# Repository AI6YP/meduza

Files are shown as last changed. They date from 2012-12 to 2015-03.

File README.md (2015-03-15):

## Meduza

Miniature control/logger board. Part of the Naut /nøyːt/ project.

### PCB v1

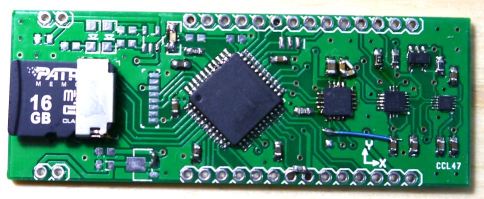
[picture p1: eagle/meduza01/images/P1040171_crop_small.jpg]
Meduza PCB top

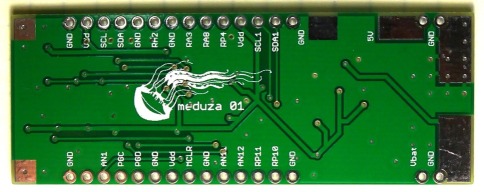
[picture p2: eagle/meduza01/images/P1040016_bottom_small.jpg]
Meduza PCB bottom


[Schematic (PDF)](eagle/meduza01/meduza01.pdf)

#### Features
 * Microchip microcontroller: [PIC24FJ64GA104](http://www.microchip.com/mymicrochip/filehandler.aspx?ddocname=en544252) / [DSPIC33EP128MC204](http://www.microchip.com/mymicrochip/filehandler.aspx?ddocname=en556386)
 * IRDA transceiver (2 Mibit/s) [TFDU6300](http://media.digikey.com/pdf/Data%20Sheets/Vishay%20Semiconductors/TFDU6300.pdf)
 * 3D Magnetometer [MAG3110L](http://cache.freescale.com/files/sensors/doc/data_sheet/MAG3110.pdf)
 * 3D Accelerometer [MMA8452QL](http://cache.freescale.com/files/sensors/doc/data_sheet/MMA8452Q.pdf)
 * 3D Giro [L3G4200D](http://www.st.com/web/en/resource/technical/document/datasheet/CD00265057.pdf)
 * temperature sensor [MCP9800](http://www.microchip.com/mymicrochip/filehandler.aspx?ddocname=en021183)
 * 1-cell LiPo battery PMIC [MCP73831T](http://www.microchip.com/mymicrochip/filehandler.aspx?ddocname=en025112)
 * microSD card socket (up-to 32GB)
 * analog/digital IO for externals sensors
 * Inductive charging circuitry (external)

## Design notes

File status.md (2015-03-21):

## Prototypes

### v1.03
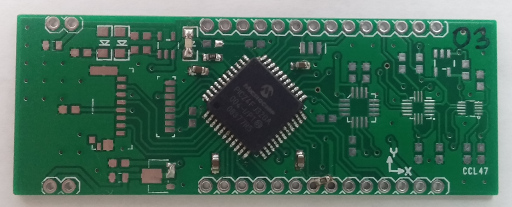
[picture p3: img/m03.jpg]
Meduza v1.03


* [PIC24FJ32GA004](http://ww1.microchip.com/downloads/en/DeviceDoc/39881e.pdf) - [3003h Errata](http://ww1.microchip.com/downloads/en/DeviceDoc/80000470h.pdf)

### v1.04
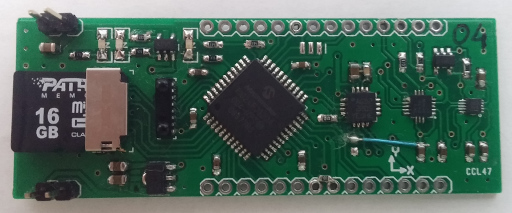
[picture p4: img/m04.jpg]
Meduza v1.04


* [PIC24FJ32GA004](http://ww1.microchip.com/downloads/en/DeviceDoc/39881e.pdf) - [3003h Errata](http://ww1.microchip.com/downloads/en/DeviceDoc/80000470h.pdf)
* IRDA transceiver (2 Mibit/s) [TFDU6300](http://media.digikey.com/pdf/Data%20Sheets/Vishay%20Semiconductors/TFDU6300.pdf)
* 3D Magnetometer [MAG3110L](http://cache.freescale.com/files/sensors/doc/data_sheet/MAG3110.pdf)
* 3D Accelerometer [MMA8452QL](http://cache.freescale.com/files/sensors/doc/data_sheet/MMA8452Q.pdf)
* 3D Giro [L3G4200D](http://www.st.com/web/en/resource/technical/document/datasheet/CD00265057.pdf)
* temperature sensor [MCP9800](http://www.microchip.com/mymicrochip/filehandler.aspx?ddocname=en021183)
* 1-cell LiPo battery PMIC [MCP73831T](http://www.microchip.com/mymicrochip/filehandler.aspx?ddocname=en025112)
* microSD card socket (up-to 32GB)

### v1.05
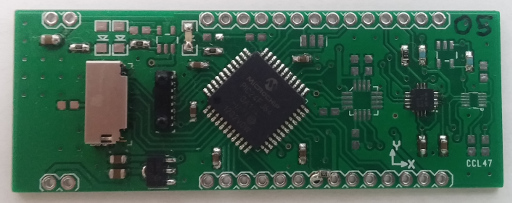
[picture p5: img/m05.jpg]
Meduza v1.05


* [PIC24FJ64GA004](http://ww1.microchip.com/downloads/en/DeviceDoc/39881e.pdf) - new
* IRDA transceiver (2 Mibit/s) [TFDU6300](http://media.digikey.com/pdf/Data%20Sheets/Vishay%20Semiconductors/TFDU6300.pdf)
* -
* 3D Accelerometer [MMA8452QL](http://cache.freescale.com/files/sensors/doc/data_sheet/MMA8452Q.pdf)
* -
* -
* -
* microSD card socket (up-to 32GB)

### v1.06
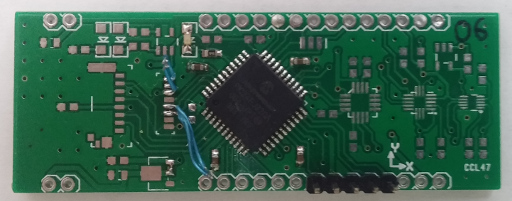
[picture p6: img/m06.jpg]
Meduza v1.06


* [PIC24FJ32GA004](http://ww1.microchip.com/downloads/en/DeviceDoc/39881e.pdf) - [3003h Errata](http://ww1.microchip.com/downloads/en/DeviceDoc/80000470h.pdf)

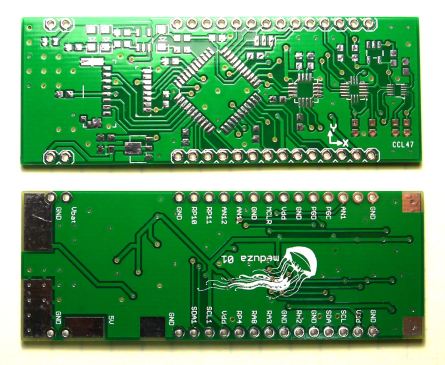
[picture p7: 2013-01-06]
eagle/meduza01/images/P1040016_small.jpg

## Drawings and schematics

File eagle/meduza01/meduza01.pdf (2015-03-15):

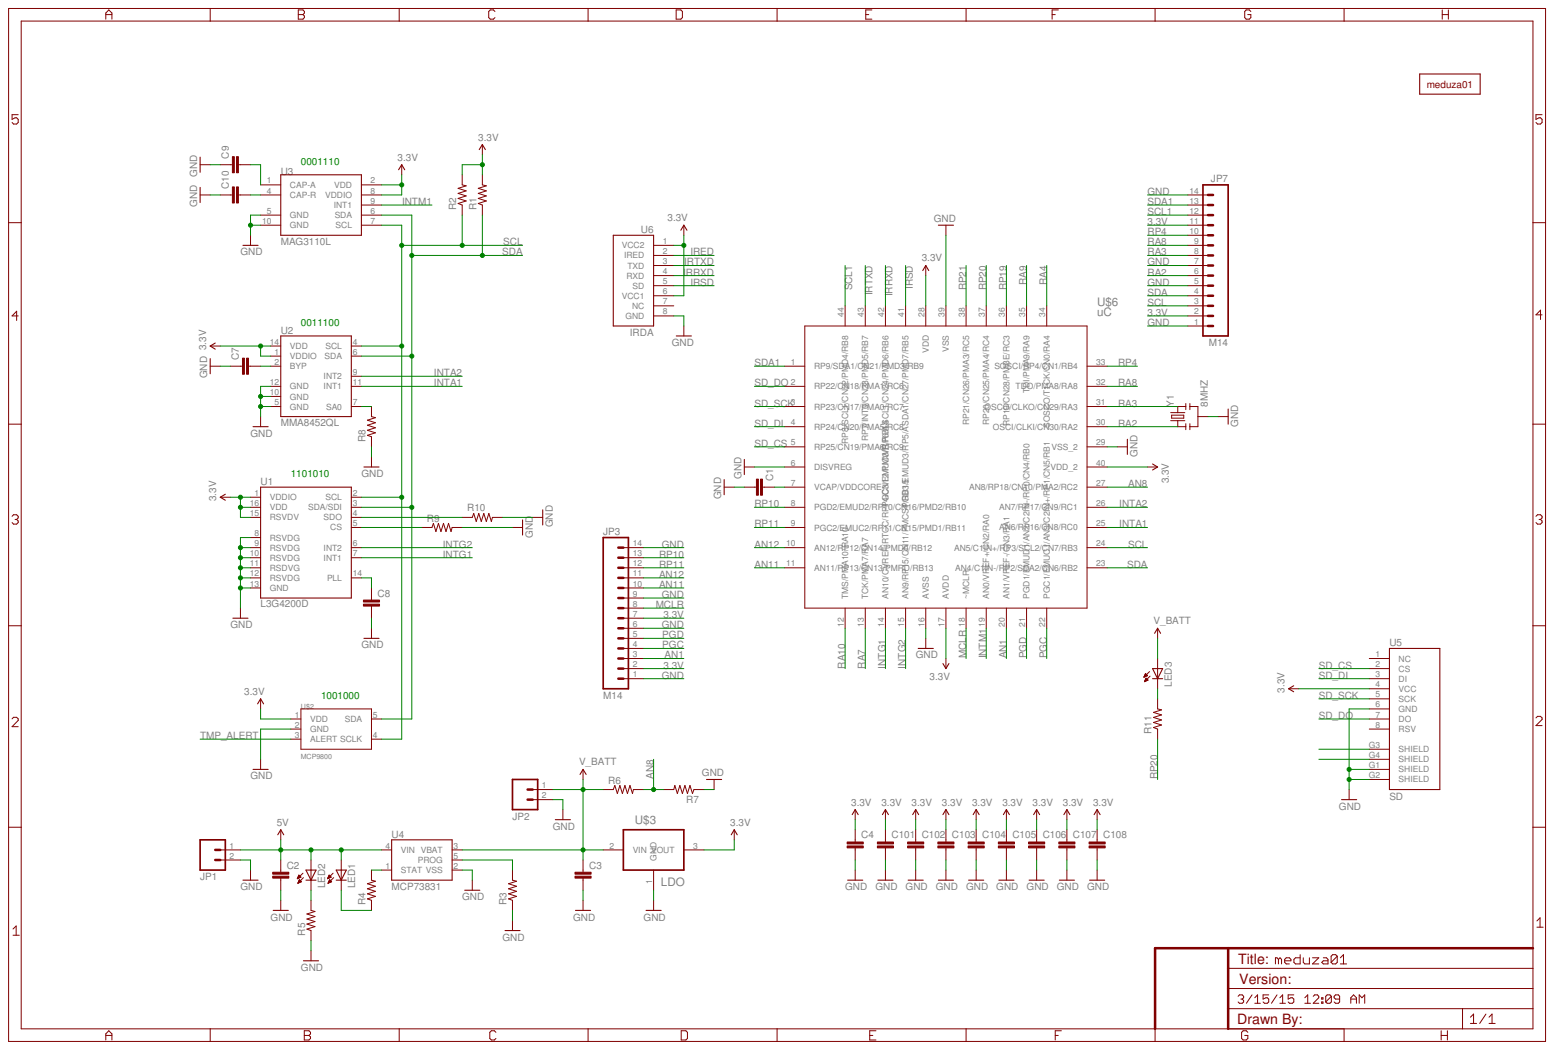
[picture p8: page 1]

GND GND

Drawn By: Title: Version:

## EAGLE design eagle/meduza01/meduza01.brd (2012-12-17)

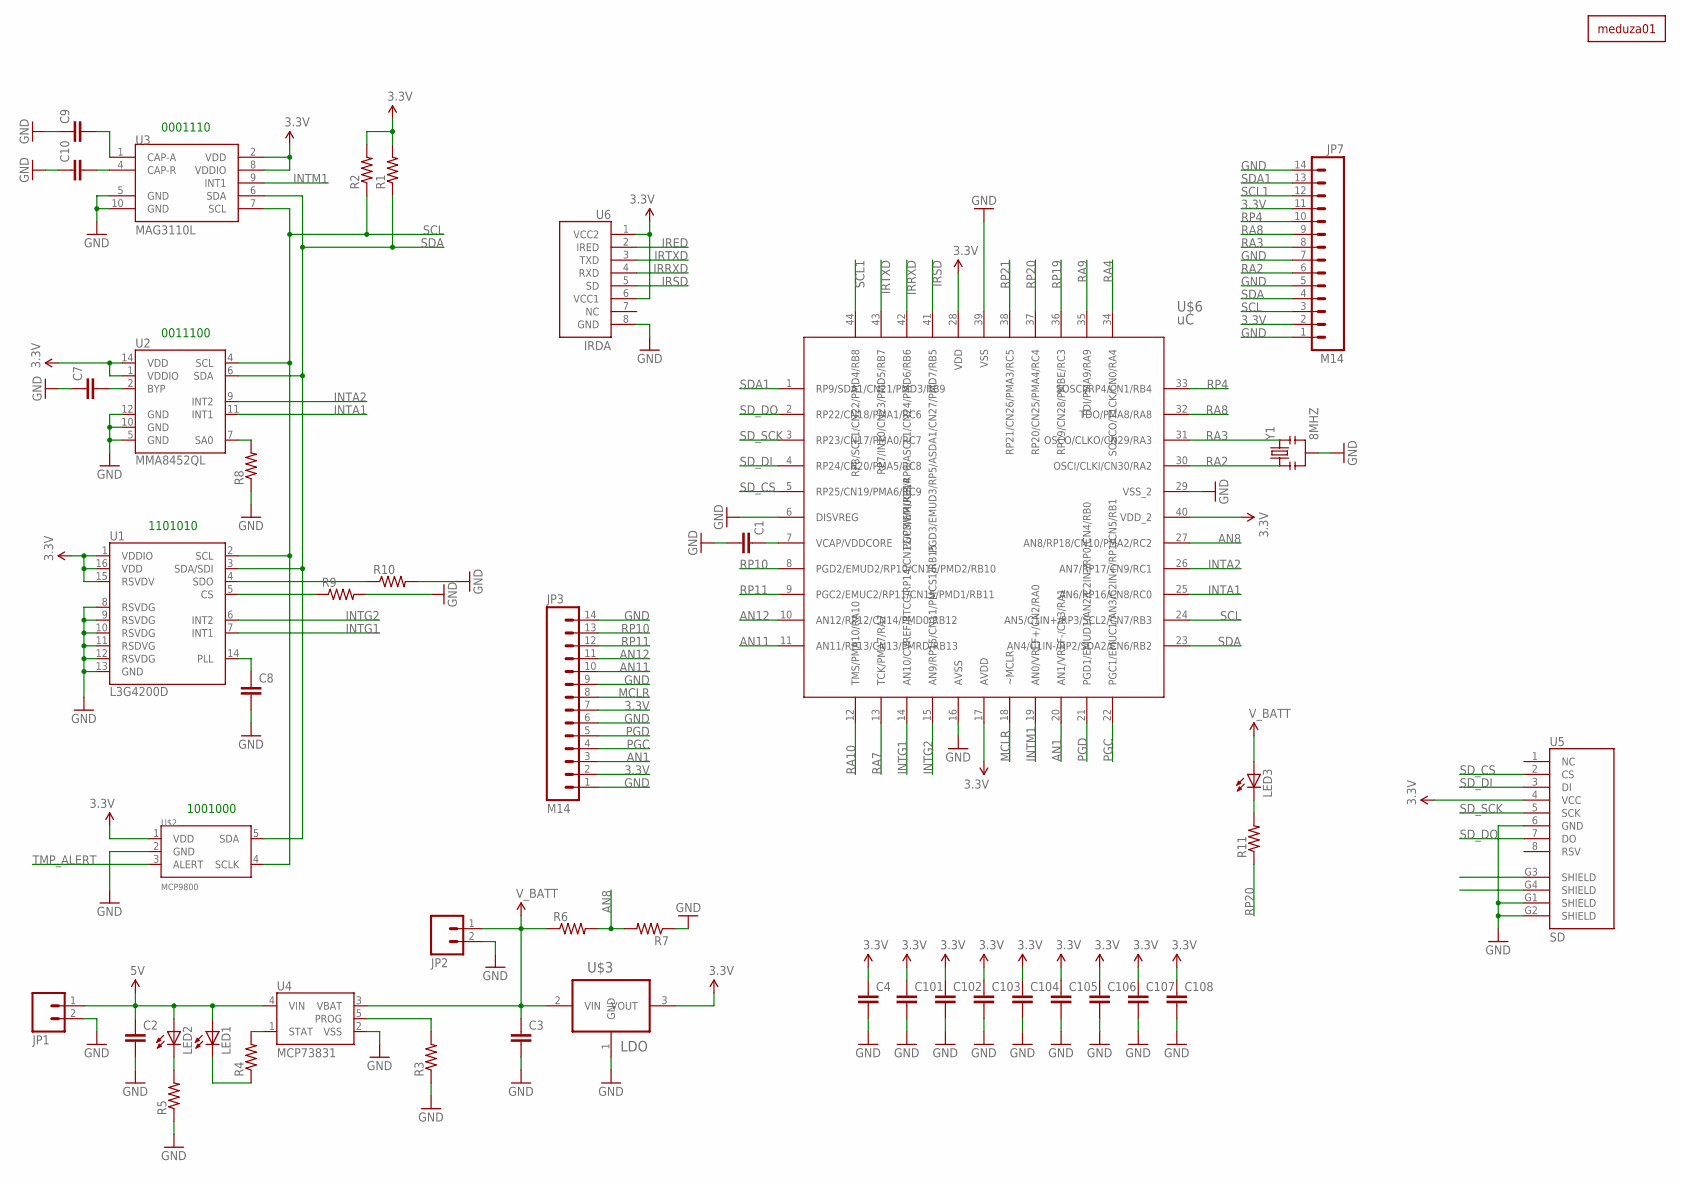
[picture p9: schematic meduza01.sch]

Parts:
C1, C4, C7, C8, C9, C10, C101, C102, C103, C104, C105, C106, C107, C108: CAP0603; 0603
C2, C3: CAP0805; 0805
JP1, JP2: M02PTH; 1X02
JP3, JP7: M14; 1X14
LED1, LED2, LED3: LED1206; LED-1206
R1, R2, R3, R4, R5, R6, R7, R8, R9, R10, R11: RESISTOR0603; 0603
U1: L3G4200D; LGA16-4X4
U2: MMA8452QL; QFN-16_0.5MM-EXTRA
U3: MAG3110L; DFN-10-EXTRA
U4: MCP73831; SOT23-5
U5: SD; MOLEX-SD-47309
U6: IRDA; TFDU6300
U$1: MEDUZA01
U$2: MCP9800; SOT23-5
U$3: LDO; SOT89R
U$6: uC; QFP80P1200X1200X120-44N
Y1: 8MHZ; RESONATOR-SMD

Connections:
3.3V: C4.1, C101.1, C102.1, C103.1, C104.1, C105.1, C106.1, C107.1, C108.1, JP3.2, JP3.7, JP7.2, JP7.11, R1.2, R2.2, U1.1 (VDDIO), U1.15 (RSVDV), U1.16 (VDD), U2.1 (VDDIO), U2.14 (VDD), U3.2 (VDD), U3.8 (VDDIO), U5.4 (VCC), U6.1 (VCC2), U6.6 (VCC1), U$2.1 (VDD), U$3.3 (VOUT), U$6.17 (AVDD), U$6.28 (VDD), U$6.40 (VDD_2)
5V: C2.1, JP1.1, LED1.A, LED2.A, U4.4 (VIN)
ABYP: C7.2, U2.2 (BYP)
AN1: JP3.3, U$6.20 (AN1/VREF-/CN3/RA1)
AN8: R6.2, R7.2, U$6.27 (AN8/RP18/CN10/PMA2/RC2)
AN11: JP3.10, U$6.11 (AN11/RP13/CN13/PMRD/RB13)
AN12: JP3.11, U$6.10 (AN12/RP12/CN14/PMD0/RB12)
GCS: R9.1, U1.5 (CS)
GND: C1.2, C2.2, C3.2, C4.2, C7.1, C8.2, C9.1, C10.1, C101.2, C102.2, C103.2, C104.2, C105.2, C106.2, C107.2, C108.2, JP1.2, JP2.2, JP3.1, JP3.6, JP3.9, JP3.14, JP7.1, JP7.5, JP7.7, JP7.14, R3.1, R5.1, R7.1, R8.1, R9.2, R10.2, U1.8 (RSVDG), U1.9 (RSVDG), U1.10 (RSVDG), U1.11 (RSDVG), U1.12 (RSVDG), U1.13 (GND), U2.5 (GND), U2.10 (GND), U2.12 (GND), U3.5 (GND), U3.10 (GND), U4.2 (VSS), U5.6 (GND), U5.G1 (SHIELD), U5.G2 (SHIELD), U6.8 (GND), U$2.2 (GND), U$3.1 (GND), U$6.6 (DISVREG), U$6.16 (AVSS), U$6.29 (VSS_2), U$6.39 (VSS), Y1.2
GPLL: C8.1, U1.14 (PLL)
GSDO: R10.1, U1.4 (SDO)
INTA1: U2.11 (INT1), U$6.25 (AN6/RP16/CN8/RC0)
INTA2: U2.9 (INT2), U$6.26 (AN7/RP17/CN9/RC1)
INTG1: U1.7 (INT1), U$6.14 (AN10/CVREF/RTCC/RP14/CN12/PMWR/RB14)
INTG2: U1.6 (INT2), U$6.15 (AN9/RP15/CN11/PMCS1/RB15)
INTM1: U3.9 (INT1), U$6.19 (AN0/VREF+/CN2/RA0)
IRED: U6.2 (IRED)
IRRXD: U6.4 (RXD), U$6.42 (PGC3/EMUC3/RP6/ASCL1/CN24/PMD6/RB6)
IRSD: U6.5 (SD), U$6.41 (PGD3/EMUD3/RP5/ASDA1/CN27/PMD7/RB5)
IRTXD: U6.3 (TXD), U$6.43 (RP7/INT0/CN23/PMD5/RB7)
MCAPA: C9.2, U3.1 (CAP-A)
MCAPR: C10.2, U3.4 (CAP-R)
MCLR: JP3.8, U$6.18 (~MCLR)
unnamed: C1.1, U$6.7 (VCAP/VDDCORE)
unnamed: LED3.C, R11.2
unnamed: LED1.C, R4.1
unnamed: LED2.C, R5.2
PGC: JP3.4, U$6.22 (PGC1/EMUC1/AN3/C2IN+/RP1/CN5/RB1)
PGD: JP3.5, U$6.21 (PGD1/EMUD1/AN2/C2IN-/RP0/CN4/RB0)
PROG: R3.2, U4.5 (PROG)
RA2: JP7.6, U$6.30 (OSCI/CLKI/CN30/RA2), Y1.1
RA3: JP7.8, U$6.31 (OSCO/CLKO/CN29/RA3), Y1.3
RA4: U$6.34 (SOSCO/T1CK/CN0/RA4)
RA7: U$6.13 (TCK/PMA7/RA7)
RA8: JP7.9, U$6.32 (TDO/PMA8/RA8)
RA9: U$6.35 (TDI/PMA9/RA9)
RA10: U$6.12 (TMS/PMA10/RA10)
RP4: JP7.10, U$6.33 (SOSCI/RP4/CN1/RB4)
RP10: JP3.13, U$6.8 (PGD2/EMUD2/RP10/CN16/PMD2/RB10)
RP11: JP3.12, U$6.9 (PGC2/EMUC2/RP11/CN15/PMD1/RB11)
RP19: U$6.36 (RP19/CN28/PMBE/RC3)
RP20: R11.1, U$6.37 (RP20/CN25/PMA4/RC4)
RP21: U$6.38 (RP21/CN26/PMA3/RC5)
SA0: R8.2, U2.7 (SA0)
SCL: JP7.3, R2.1, U1.2 (SCL), U2.4 (SCL), U3.7 (SCL), U$2.4 (SCLK), U$6.24 (AN5/C1IN+/RP3/SCL2/CN7/RB3)
SCL1: JP7.12, U$6.44 (RP8/SCL1/CN22/PMD4/RB8)
SDA: JP7.4, R1.1, U1.3 (SDA/SDI), U2.6 (SDA), U3.6 (SDA), U$2.5 (SDA), U$6.23 (AN4/C1IN-/RP2/SDA2/CN6/RB2)
SDA1: JP7.13, U$6.1 (RP9/SDA1/CN21/PMD3/RB9)
SD_CS: U5.2 (CS), U$6.5 (RP25/CN19/PMA6/RC9)
SD_DI: U5.3 (DI), U$6.4 (RP24/CN20/PMA5/RC8)
SD_DO: U5.7 (DO), U$6.2 (RP22/CN18/PMA1/RC6)
SD_SCK: U5.5 (SCK), U$6.3 (RP23/CN17/PMA0/RC7)
STAT: R4.2, U4.1 (STAT)
TMP_ALERT: U$2.3 (ALERT)
V_BATT: C3.1, JP2.1, LED3.A, R6.1, U4.3 (VBAT), U$3.2 (VIN)

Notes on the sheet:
1001000
1101010
0011100
0001110

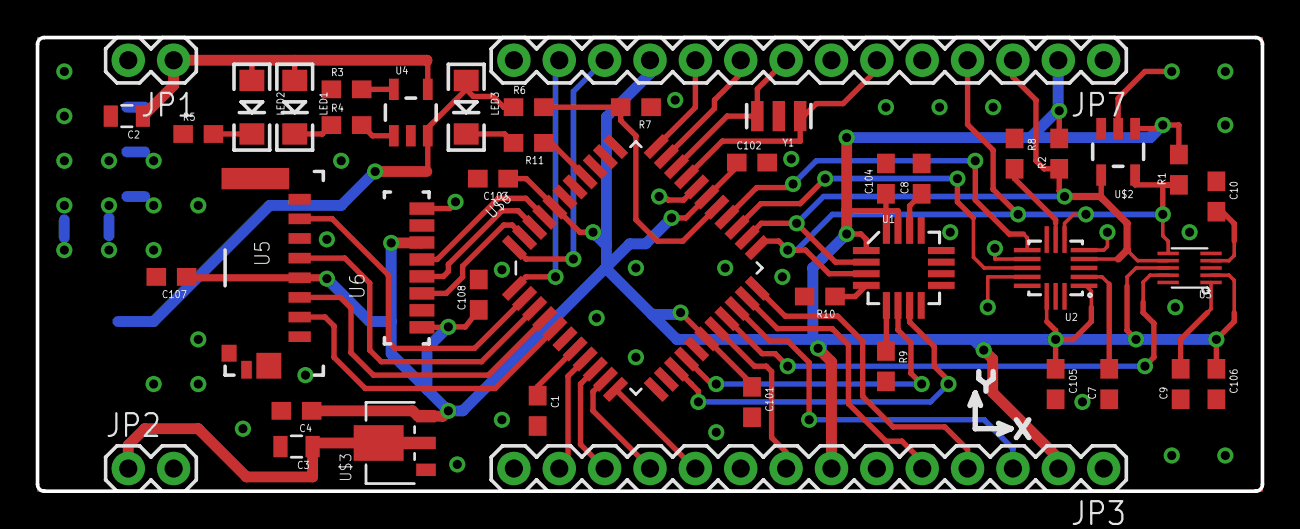
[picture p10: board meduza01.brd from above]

Board: 2 copper layers, 68.6 x 25.4 mm, 45 parts (1 on the bottom side), 47 nets.

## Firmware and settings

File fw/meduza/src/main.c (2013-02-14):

/* 
 * File:   main.c
 *
 * $Id$
 */

// #include <stdlib.h>
#include <xc.h>
#include <stdint.h>          /* For uint32_t definition */
#include <stdbool.h>         /* For true/false definition */
// #include <p24Fxxxx.h>
#include "config.h"
#include "status.h"

_CONFIG1 (JTAGEN_OFF & GCP_OFF & GWRP_OFF & COE_OFF & FWDTEN_OFF & ICS_PGx2)
_CONFIG2 (FNOSC_FRCPLL)

unsigned rc_last_time;
unsigned rc_state;
unsigned long rc_command;
unsigned state;
unsigned data_counter;
unsigned status; // StatusLED state

void Init_CLK (void) {
	// CLKDIV [2:0] = RCDIV = 0 (FRC = 8MHz)
	CLKDIV = 0x0000;

	__builtin_write_OSCCONH (1);
	__builtin_write_OSCCONL (1);

	// Oscillator Switch Enable bit
	OSCCONbits.OSWEN = 1;
}

void T1_Init  (void) {
	TMR1            = 0;           // clear timer1 register
	PR1             = TMR1_PERIOD; // set period1 register
	T1CONbits.TSYNC = 0; // 
	T1CONbits.TCKPS = TMR1_PRE; // ( x, x/8, x/64, x/256 )
	T1CONbits.TCS   = 0; // set internal clock source
//	IPC0bits.T1IP   = 4; // set priority level
	IFS0bits.T1IF   = 0; // clear interrupt flag
	IEC0bits.T1IE   = 1; // enable interrupts
//	SRbits.IPL      = 3; // enable CPU priority levels 4-7
	T1CONbits.TON   = 1; // start the timer
}

void T3_Init  (void) {
	T2CONbits.T32   = 0;
	T3CONbits.TCKPS = TMR3_PRE;
	T3CONbits.TCS   = 0; // set internal clock source
//	T3CONbits.TGATE = 0;
	TMR3            = 0;      // clear timer register
	PR3             = 0xFFFF; // set period register
//	IPC0bits.T1IP   = 4; // set priority level
//	IFS0bits.T1IF   = 0; // clear interrupt flag
//	IEC0bits.T1IE   = 1; // enable interrupts
//	SRbits.IPL      = 3; // enable CPU priority levels 4-7
	T3CONbits.TON   = 1; // start the timer
}

void IC1_Init (void) {
	// Remote Control pulse rate: Period 27us = 37KHz
	// TMR3 init ???

	// IC1CON [2:0] = ICM   = 5 (Capture mode, every 16th rising edge)
	// IC1CON [6:5] = ICI   = 0 (Interrupt on every capture event)
	// IC1CON   [7] = ICTMR = 0 (TMR3)
	IC1CON = 0x0005;

	// clear IC1 interrupt flag
	IFS0bits.IC1IF = 0;
	// enable interrupts
	IEC0bits.IC1IE = 1;
}

/*
void TestPorts (void) {
    unsigned i, j;
    TRISA = 0; // on
    TRISB = 0; // on
    TRISC = 0; // on
    j = 0;
    while (1) {
        LATA = j;
        LATB = j;
        LATC = j;
        for (i = 0; i < 50; i++) {}
        j++;
    }
}
*/

void I2C_wait_for_idle (void) {
	while (I2C2STATbits.TRSTAT); // Wait for bus Idle
}

void I2C_write (unsigned char data) {
	I2C2TRN = data;
	while (I2C2STATbits.TBF);
	I2C_wait_for_idle ();
}

void I2C_ByteWrite (unsigned char a0, unsigned char a1, unsigned char d) {
	unsigned i;
	I2C_wait_for_idle ();
	I2C2CONbits.SEN = 1; while (I2C2CONbits.SEN); // Start
	I2C_write (a0); // 7-bit address + rw=0 (write)
	if (!I2C2STATbits.ACKSTAT) {
		I2C_wait_for_idle ();
		I2C_write (a1);
		if (!I2C2STATbits.ACKSTAT) {
			I2C_wait_for_idle ();
			I2C_write (d);
		}
	}
	I2C_wait_for_idle ();
	I2C2CONbits.PEN = 1; while (I2C1CONbits.PEN); // Stop
	I2C_wait_for_idle ();
	for (i = 0; i < 100; i++) { }
}

unsigned I2C_ByteRead (unsigned acc) { // 0 - ACC (continue)  1 - NAC (finish)
	unsigned tmp;
	I2C2CONbits.RCEN = 1; //  and transmits the data from the requested register.
	I2C2CONbits.ACKDT = acc;
	while(!I2C2STATbits.RBF); // Wait for receive bufer to be full
	tmp = I2C2RCV;
	I2C2CONbits.ACKEN = 1; // ACK
	while (I2C2CONbits.ACKEN); // wait for ACK to complete
	I2C_wait_for_idle ();
	return tmp;
}

unsigned I2C_Read (unsigned char a0, unsigned char a1, unsigned char length) {
	unsigned i, tmp = 0;
	I2C_wait_for_idle ();
	I2C2CONbits.SEN = 1; while (I2C2CONbits.SEN); // Start
	I2C_write (a0); // 7-bit address + rw=0 (write)
	if (!I2C2STATbits.ACKSTAT) { // slave sends an acknowledgement
		I2C_wait_for_idle ();
		// master transmits the address of the register to read
		I2C_write (a1); // DR_STATUS
		if (!I2C2STATbits.ACKSTAT) { // slave sends an acknowledgement
			I2C_wait_for_idle ();
			I2C2CONbits.RSEN = 1; while (I2C2CONbits.RSEN); // Restart
			// followed by the slave address with the R/W bit set to “1” for a read from the previously selected register
			I2C_write (a0 | 1); // 0x0E + read=1
			if (!I2C2STATbits.ACKSTAT) { // slave then acknowledges
				for (i = 0; i < (length - 1); i++) {
					tmp = ((I2C_ByteRead (0)) << 8) | (tmp >> 8);
				}
				tmp = ((I2C_ByteRead (1)) << 8) | (tmp >> 8);
			}
		}
	}
	// followed by a stop condition (SP) signaling the end of transmission.
	I2C2CONbits.PEN = 1; while (I2C1CONbits.PEN); // Stop
	I2C_wait_for_idle ();
	for (i = 0; i < 10; i++) { }
}

void I2C_Read_Head (unsigned char a0, unsigned char a1) {
	unsigned i;
	I2C_wait_for_idle ();
	I2C2CONbits.SEN = 1; while (I2C2CONbits.SEN); // Start
	I2C_write (a0); // 7-bit address + rw=0 (write)
	if (!I2C2STATbits.ACKSTAT) { // slave sends an acknowledgement
		I2C_wait_for_idle ();
		// master transmits the address of the register to read
		I2C_write (a1); // DR_STATUS
		if (!I2C2STATbits.ACKSTAT) { // slave sends an acknowledgement
			I2C_wait_for_idle ();
			I2C2CONbits.RSEN = 1; while (I2C2CONbits.RSEN); // Restart
			// followed by the slave address with the R/W bit set to “1” for a read from the previously selected register
			I2C_write (a0 | 1); // 0x0E + read=1
			if (!I2C2STATbits.ACKSTAT) { // slave then acknowledges
			}
		}
	}
}

unsigned I2C_Read_Body (unsigned acc) {
	unsigned hi, lo;
	lo = I2C_ByteRead (0);
	hi = I2C_ByteRead (acc);
	return (hi << 8) | lo;
}

void I2C_Read_Tail (void) {
	unsigned i, tmp = 0;
	tmp =  I2C_ByteRead (1);
	// followed by a stop condition (SP) signaling the end of transmission.
	I2C2CONbits.PEN = 1; while (I2C1CONbits.PEN); // Stop
	I2C_wait_for_idle ();
	for (i = 0; i < 10; i++) { }
}

void I2C_Read_SD_Write (unsigned char a0, unsigned char a1, unsigned char length) {
	unsigned i, tmp;
	I2C_wait_for_idle ();
	I2C2CONbits.SEN = 1; while (I2C2CONbits.SEN); // Start
	I2C_write (a0); // 7-bit address + rw=0 (write)
	if (!I2C2STATbits.ACKSTAT) { // slave sends an acknowledgement
		I2C_wait_for_idle ();
		// master transmits the address of the register to read
		I2C_write (a1); // DR_STATUS
		if (!I2C2STATbits.ACKSTAT) { // slave sends an acknowledgement
			I2C_wait_for_idle ();
			I2C2CONbits.RSEN = 1; while (I2C2CONbits.RSEN); // Restart
			// followed by the slave address with the R/W bit set to “1” for a read from the previously selected register
			I2C_write (a0 | 1); // 0x0E + read=1
			if (!I2C2STATbits.ACKSTAT) { // slave then acknowledges
				for (i = 0; i < (length - 1); i++) {
					I2C2CONbits.RCEN = 1; //  and transmits the data from the requested register.
					I2C2CONbits.ACKDT = 0;
					while(!I2C2STATbits.RBF); // Wait for receive bufer to be full
					tmp = I2C2RCV;
					SD_write_data (tmp);
					I2C2CONbits.ACKEN = 1; // ACK
					while (I2C2CONbits.ACKEN); // wait for ACK to complete
					I2C_wait_for_idle ();
				}
				I2C2CONbits.RCEN  = 1; //  and transmits the data from the requested register.
				I2C2CONbits.ACKDT = 1;
				while(!I2C2STATbits.RBF); // Wait for receive bufer to be full
				tmp = I2C2RCV;
				SD_write_data (tmp);
				I2C2CONbits.ACKEN = 1; // NACK
				while(I2C2CONbits.ACKEN); // wait for ACK to complete
				I2C_wait_for_idle ();
			}
		}
	}
	// followed by a stop condition (SP) signaling the end of transmission.
	I2C2CONbits.PEN = 1; while (I2C1CONbits.PEN); // Stop
	I2C_wait_for_idle ();
	for (i = 0; i < 100; i++) { }
}

void I2C_Init (void) {
//	TRISBbits.TRISB2 = 0; // on SDA2
	I2C2BRG = 15; // 100KHz 157
	I2C2CON = 0x1200;
	I2C2RCV = 0x0000;
	I2C2TRN = 0x0000;
	// Now we can enable the peripheral
	I2C2CON = 0x9200;

	I2C_Read (I2C_ACC, ACC_STATUS, 1); // Read ACC to test I2C
}

unsigned ACC_state = 0;

void ACC_Start (void) {
	unsigned tmp;
	// CTRL_REG1 [1] = ACTIVE = 0
	I2C_ByteWrite (I2C_ACC, ACC_CTRL_REG1, 0x00);

	// F_SETUP [] = F_MODE = 0
	I2C_ByteWrite (I2C_ACC, ACC_F_SETUP,   0x00);

//	I2C_ByteWrite (I2C_ACC, ACC_F_SETUP,   (0x00));

	// F_SETUP [7:6] = F_MODE = 2 (Fill Mode)
	// F_SETUP [5:0] = F_WMRK = 1
	I2C_ByteWrite (I2C_ACC, ACC_F_SETUP,   (0x80 | 0x01));

	// CTRL_REG4 [6] = INT_EN_FIFO = 1
	I2C_ByteWrite (I2C_ACC, ACC_CTRL_REG4, 0x40);

	// CTRL_REG5 [6] = INT_CFG_FIFO = 1 (INT1)
	I2C_ByteWrite (I2C_ACC, ACC_CTRL_REG5, 0x40);

	// Full Scale Range = 0 (2g)
	I2C_ByteWrite (I2C_ACC, ACC_XYZ_DATA_CFG, 0x00);

	// CTRL_REG3 [1] = IPOL = 1 (Active High)
	I2C_ByteWrite (I2C_ACC, ACC_CTRL_REG3, 0x02);

	// CTRL_REG1 [1] = ACTIVE = 1
	I2C_ByteWrite (I2C_ACC, ACC_CTRL_REG1, 0x01);

	I2C_Read_Head (I2C_ACC, ACC_STATUS);
	tmp = I2C_ByteRead (0); // ACC_STATUS read
//	while (1) {
//		while (!PORTCbits.RC0) { }
//		I2C_Read (I2C_ACC, ACC_STATUS, 193);
//	}
}

void ACC_Stop (void) {
	// CTRL_REG1 [1] = ACTIVE = 0
	I2C_ByteWrite (I2C_ACC, ACC_CTRL_REG1, 0x00);
}

unsigned ACC_Read (long count) {
	unsigned dat, i, tmp;
	if (count == 0) {
		ACC_Start ();
	}
	if (ACC_state == 0) { // x
		while (PORTCbits.RC0) { }
		while (!PORTCbits.RC0) { }

		dat = I2C_Read_Body (0);
		ACC_state = 1;
		return dat;
	}
	if (ACC_state == 1) { // y
		dat = I2C_Read_Body (0);
		ACC_state = 2;

		StatusLED (count & 512);

		return dat;
	}
	// z
	dat = I2C_Read_Body (1);
	// stop
	I2C2CONbits.PEN = 1; while (I2C1CONbits.PEN);
	I2C_wait_for_idle ();
	for (i = 0; i < 10; i++) { }
	// clean start
	I2C_Read_Head (I2C_ACC, ACC_STATUS);
	tmp = I2C_ByteRead (0); // ACC_STATUS read
	ACC_state = 0;
	return dat;
}

void U1_Init (void) {
	U1MODEbits.BRGH   = U1_BRGH;
	U1BRG             = U1_BRG;
	U1MODEbits.UARTEN = 1;  // U1 enable

	// IRDA section
	// U1MODEbits.IREN   = 1;  // IRDA !!!
	U1STAbits.UTXINV = 1;

	U1STAbits.UTXEN   = 1;  // transmit enable
//	RPOR4bits.RP8R    = 3;  // U1TX --> RP8 --> pin 44
//	RPOR1bits.RP2R    = 3;  // U1TX --> RP2 --> pin 23
//	RPOR9bits.RP19R   = 3;  // U1TX --> RP19 --> pin 36
//	RPOR10bits.RP21R   = 3;  // U1TX --> RP21 --> pin 38
}

void RC_StateMachine_Init (void) {
	rc_state = 0; // Idle state
	rc_command = 0;
}

unsigned long RC_StateMachine (void) {
    unsigned time, delta;
    unsigned long tmp_command;
    time = IC1BUF;
    delta = time - rc_last_time;
    rc_last_time = time;
    if (rc_state) { // counting bits
        if ((delta >= RC_ZERO_MIN) & (delta <= RC_ZERO_MAX)) {
            rc_state++;
            rc_command = rc_command << 1;
        } else if ((delta >= RC_ONE_MIN) & (delta <= RC_ONE_MAX)) {
            rc_state++;
            rc_command = rc_command << 1;
            rc_command = rc_command | 1;
        }
        if (rc_state == 32) {
            rc_state = 0;
            tmp_command = rc_command;
            rc_command = 0;
            return tmp_command;
        }
    } else { // Idle
        if ((delta >= RC_START_MIN) & (delta <= RC_START_MAX)) {
            rc_state = 1;
        }
    }
    return 0;
}

/* void ADC_Init (void) {
    // Select how conversion results are
    // presented in the buffer
    AD1CON1bits.FORM = 0; // Integer (0000 00dd dddd dddd)
    // Select the appropriate sample/conversion sequence
    AD1CON1bits.SSRC = 3; // Internal counter ends sampling and starts conversion (auto-convert)
//    AD1CON1bits.ASAM = 1; // Sampling begins immediately after last conversion completes. SAMP bit is auto-set.
    // Select port AN1 pins as analog input
    AD1PCFG = 0xFFFF;
    AD1PCFGbits.PCFG1 = 0;
    // Set up A/D Channel Select Register to convert AN1 on Mux A input
    AD1CHS = 1;
    // Select voltage reference source to match
    // expected range on analog inputs
    AD1CON2bits.VCFG = 0;
    // Select the analog conversion clock to
    // match desired data rate with processor
    // clock
    AD1CON3bits.ADCS = ADC_CONV_PERIOD;
    AD1CON3bits.SAMC = 1;
    AD1CON3bits.ADRC = 0; // Clock derived from system clock
    // and
    // AD1CON3<12:8>).
    // Select interrupt rate
    AD1CON2bits.SMPI = 0; // Interrupts at the completion of conversion for each sample/convert sequence
    // Clear the A/D interrupt flag bit
    IFS0bits.AD1IF = 0;
    // Set the A/D interrupt enable bit
    IEC0bits.AD1IE = 1;
    // Turn on A/D module
//    AD1CON1bits.ADON = 1;
//    AD1CON1bits.SAMP = 1;
//    AD1CON1bits.ASAM = 1; // Sampling begins immediately after last conversion completes. SAMP bit is auto-set.
}
*/

void Init_Ports (void) {
	// SD_DO   <-- RP22, RC6    MISO
	// SD_SCK  <-- RP23, RC7    SCLK
	// SD_DI   --> RP24, RC8    MOSI
	// SD_CS   <-- RP25, RC9    SD_CS
	// INTA1   --> AN6, RC0, RP16
	// INTA2   --> AN7, RP17, RC1 -- unused
	// test    <-- AN1, RA1
	// RP5 = IRSD  <-- RB5
	// TRISBbits.TRISB2 = 0; // on SDA2


	// ******************************************************** Ports
	// RA1 = test
	TRISA = 0xFFFD;
	// RB5 = IRSD
	// RB2 = SDA2
	TRISB = 0xFFDB; // I2C bug workaround
//	LATB  = 0xFFFB; // I2C bug workaround
//	TRISB = 0xFFDF;
//	TRISB = 0xFFDB;
	// RC4 = Status LED
	// RC9 = SD_CS
	TRISC = 0xFDEF;
	// RC4 = Status LED = 1 (off)
	LATC  = 0x0010;

	// ******************************************************** AN Pins
	// AN6 = digital mode INTA1
	AD1PCFGbits.PCFG6 = 1;
	// AN1 = digital mode (test)
	AD1PCFGbits.PCFG1 = 1;

	// ******************************************************** RP Inputs
	// RPINR0  [12:8] = INT1   = 16 (RP16) INTA1 <-- RC0
	RPINR0  = 0x1000;
	// RPINR18 [12:8] = U1CTSR = 31 (unselected)
	// RPINR18  [4:0] = U1RXR  = 6  (RP6)  IRRXD <-- RB6
	RPINR18 = 0x1F06;
	// RPINR7  [12:8] = IC2    = 31 (Stub)
	// RPINR7   [4:0] = IC1    = 6  (RP6)  IRRXD <-- RB6
	RPINR7  = 0x1F06;
	// RPINR7  [12:8] = SCK1   = 31 (Stub)
	// RPINR7   [4:0] = SDI1   = 22 (RP22) SD_DO <-- RC6  MISO
	RPINR20 = 0x1F16;

	// ******************************************************** RP Outputs
	// RPOR11  [12:8] = RP23 = 8  (SCLK) SD_SCK  <-- RC7
	// RPOR11   [4:0] = RP22 = input
	RPOR11  = 0x0800;
	// RPOR12  [12:8] = RP25 = 0 (unused)
	// RPOR12   [4:0] = RP24 = 7  (MOSI) SD_DI   <-- RC8
	RPOR12  = 0x0007;
	// RPOR3   [12:8] = RP7  = 3  (U1TX) IRTXD   <-- RB7
	RPOR3   = 0x0300;


	// INTCON2    [1] = INT1EP = 0 (@ posedge INT1)
//	INTCON2 = 0x0000;
	
	// Reset INT1 flag
//	IFS1bits.INT1IF = 0;
	
	// Enable INT1
//	IEC1bits.INT1IE = 1;
}

void __attribute__((__interrupt__)) _IC1Interrupt   (void) {
	unsigned long tmp_command;
	unsigned i, j, dat = 0;
	long count = 0;
	tmp_command = RC_StateMachine ();
	if (tmp_command) {
		if (tmp_command == 0x007FE11E) { // PLAY
			StatusShow (0b10, 2); // Morse: A .-
			SD_dump (1500);
			StatusShow (0b10, 2); // Morse: A .-
		} else if (tmp_command == 0x007FB44B) { // 0 - write regular pattern
			StatusShow (0b0001, 4); // Morse: B -...
			SD_write_head (0);
			for (j = 0; j < 100; j++) {
				SD_write_start_token ();
				for (i = 0; i < 256; i++) {
					SD_write_data (dat++);
				}
				SD_write_crc ();
			}
			SD_write_stop_token ();
			StatusShow (0b0001, 4); // Morse: B -...
		} else if (tmp_command == 0x007F9867) { // 1 - accelerometer to SD
			StatusShow (0b1010, 4); // Morse: С -.-.
			SD_write_head (0);
			for (j = 0; j < 1200; j++) {
				SD_write_start_token ();
				for (i = 0; i < 256; i++) {
					dat = ACC_Read (count++);
					SD_write_data (dat);
				}
				SD_write_crc ();
			}
			SD_write_stop_token ();
			count = 0;
			StatusShow (0b1010, 4); // Morse: С -.-.
		}
	}
	IFS0bits.IC1IF = 0; // clear IC1 interrupt flag
}

void __attribute__((__interrupt__)) _T1Interrupt    (void) {
/*
//    int ADCValue;
//    AD1PCFG = 0xFFFD; // all PORTB = Digital; RB12 = analog
    AD1CON1 = 0x00E0; // SSRC<2:0> = 111 implies internal counter ends sampling
    // and starts converting.
//    AD1CHS = 1; // Connect AN1 as S/H input.
    // in this example AN12 is the input
//    AD1CSSL = 0;
    AD1CON3 = 0x1F02; // Sample time = 31Tad, Tad = 3Tcy
    AD1CON2 = 0;
    AD1CON1bits.ADON = 1; // turn ADC ON
    AD1CON1bits.SAMP = 1; // start sampling, then after 31Tad go to conversion
//    while (!AD1CON1bits.DONE){}; // conversion done?
//    ADCValue = ADC1BUF0; // yes then get ADC value

//    while (U1STAbits.UTXBF == 1);
//    U1TXREG = ADCValue;
 */
    IFS0bits.T1IF = 0; // clear T1 interrupt flag
}

void __attribute__((__interrupt__)) _ADC1Interrupt  (void) {
    // Clear the A/D Interrupt flag bit or else the CPU will
    // keep vectoring back to the ISR
    unsigned res;
    IFS0bits.AD1IF = 0;

    res = ADC1BUF0;
    while (U1STAbits.UTXBF == 1);
    U1TXREG = res >> 8;
    while (U1STAbits.UTXBF == 1);
    U1TXREG = res;
//    AD1CON1 = 0x00E0; // SSRC<2:0> = 111 implies internal counter ends sampling
}

void __attribute__((__interrupt__)) _INT1Interrupt  (void) {
	unsigned i;

	SD_write_start_token ();

	I2C_Read_SD_Write (I2C_ACC, 1, 192);

	for (i = 0; i < 64; i++) { // dummy 0s
		SD_write_data (0);
	}

	SD_write_crc ();
	
	data_counter++;

	StatusLED (status);
	if (status) {
		status = 0;
	} else {
		status = 1;
	}

	if (data_counter >= 100) {
		ACC_Stop ();
		SD_write_stop_token ();
	}

	IFS1bits.INT1IF = 0; // Reset INT1 flag
}

int main (int argc, char** argv) {
	Init_CLK ();
	Init_Ports ();
	StatusShow (0, 1); // Morse: E .
	I2C_Init ();
	T3_Init ();
	IC1_Init ();
	U1_Init ();
	SD_Init ();
	RC_StateMachine_Init ();
	StatusShow (0, 1); // Morse: E .
	while (1) Idle ();
	return (0); // EXIT_SUCCESS);
}

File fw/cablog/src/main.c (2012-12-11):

/* 
 * File:   main.c
 *
 * $Id$
 */

#include <p24Fxxxx.h>

_CONFIG1 (JTAGEN_OFF & GCP_OFF & GWRP_OFF & COE_OFF & FWDTEN_OFF & ICS_PGx2)
_CONFIG2 (FNOSC_FRC)

#define		DELAY	1

int main(int argc, char** argv) {
    unsigned i;
    // 8MHz
    TRISA = 0xFFFF; // off
    TRISB = 0xFFFF; // off
    TRISC = 0xFFFF; // off
    AD1PCFG = 0xFFFF; // all AN pins now digital

    TRISCbits.TRISC1 = 0; // SD  = pin26 / RC1 / RP17
    TRISBbits.TRISB2 = 0; // TXD = pin23 / RB2 / RP2

    LATCbits.LATC1   = 0; // SD = 0
    LATBbits.LATB2   = 0; // TXD = 0
    for (i = 0; i < DELAY; i++) { } // delay >200 ns
    LATCbits.LATC1   = 1; // SD = 1
    for (i = 0; i < DELAY; i++) { } // delay >200 ns
    LATBbits.LATB2   = 1; // TXD = 1
    for (i = 0; i < DELAY; i++) { } // delay >200 ns
    LATCbits.LATC1   = 0; // SD = 0
    for (i = 0; i < DELAY; i++) { } // delay >200 ns
    LATBbits.LATB2   = 0; // TXD = 0

    while (1) Idle ();
}

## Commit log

2012-12-11 repo restart
    [meduza01.brd, meduza01.sch]
2012-12-17 meduza01 board files
    [meduza01.brd, meduza01.sch]
2013-01-06 Meduza PCB photo from BatchPCB foundry
2013-01-17 I2C support added
2013-01-19 new PCB photos
2013-01-23 updated SD card, IRDA interfaces for Meduza01 board
2013-02-14 minor play around I2C
2015-03-15 added schematic pdf
2015-03-21 board status images added
2015-03-21 board status text added

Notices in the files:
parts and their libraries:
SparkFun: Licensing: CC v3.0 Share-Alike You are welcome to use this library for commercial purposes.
